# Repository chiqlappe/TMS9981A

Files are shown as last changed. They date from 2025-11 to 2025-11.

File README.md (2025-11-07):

# TMS9981Aビデオカード

## 概要
* PC-8001などからTMS9981Aを制御してビデオ出力を行うための拡張基板

## 使用環境
* PC-8001+PC-8012
* PC-8001mk2/SR
* PC-8801シリーズ（未確認）

## I/Oポート
|I/O|アドレス|用途|
|:--|:--|:--|
|IN/OUT|$98|データポート|
|IN/OUT|$99|コントロールポート|

## 参考サイト
[KUNINET BLOGさん](https://kuninet.org/2019/11/23/kz80%e3%83%9e%e3%82%a4%e3%82%b3%e3%83%b3-%e5%81%bdmsx1%e3%81%b8%e3%80%9c%e3%83%93%e3%83%87%e3%82%aa%e3%83%9c%e3%83%bc%e3%83%891/)

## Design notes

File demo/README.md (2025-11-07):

# デモプログラム

## 概要
* ビデオカードの動作検証用プログラム
* PC-8001シリーズ用
* 機械語プログラム（自動実行）

## プログラム
* ```ascii.wav``` フォント出力
* ```mandel.wav``` マンデルブロ集合
* ```nyan.wav``` Nyan Cat
* ```plasma.wav``` プラズマ
* ```sprite.wav``` スプライト
  
[J.B. Langston氏によるオリジナルプログラムはこちら](https://github.com/jblang/TMS9918A)

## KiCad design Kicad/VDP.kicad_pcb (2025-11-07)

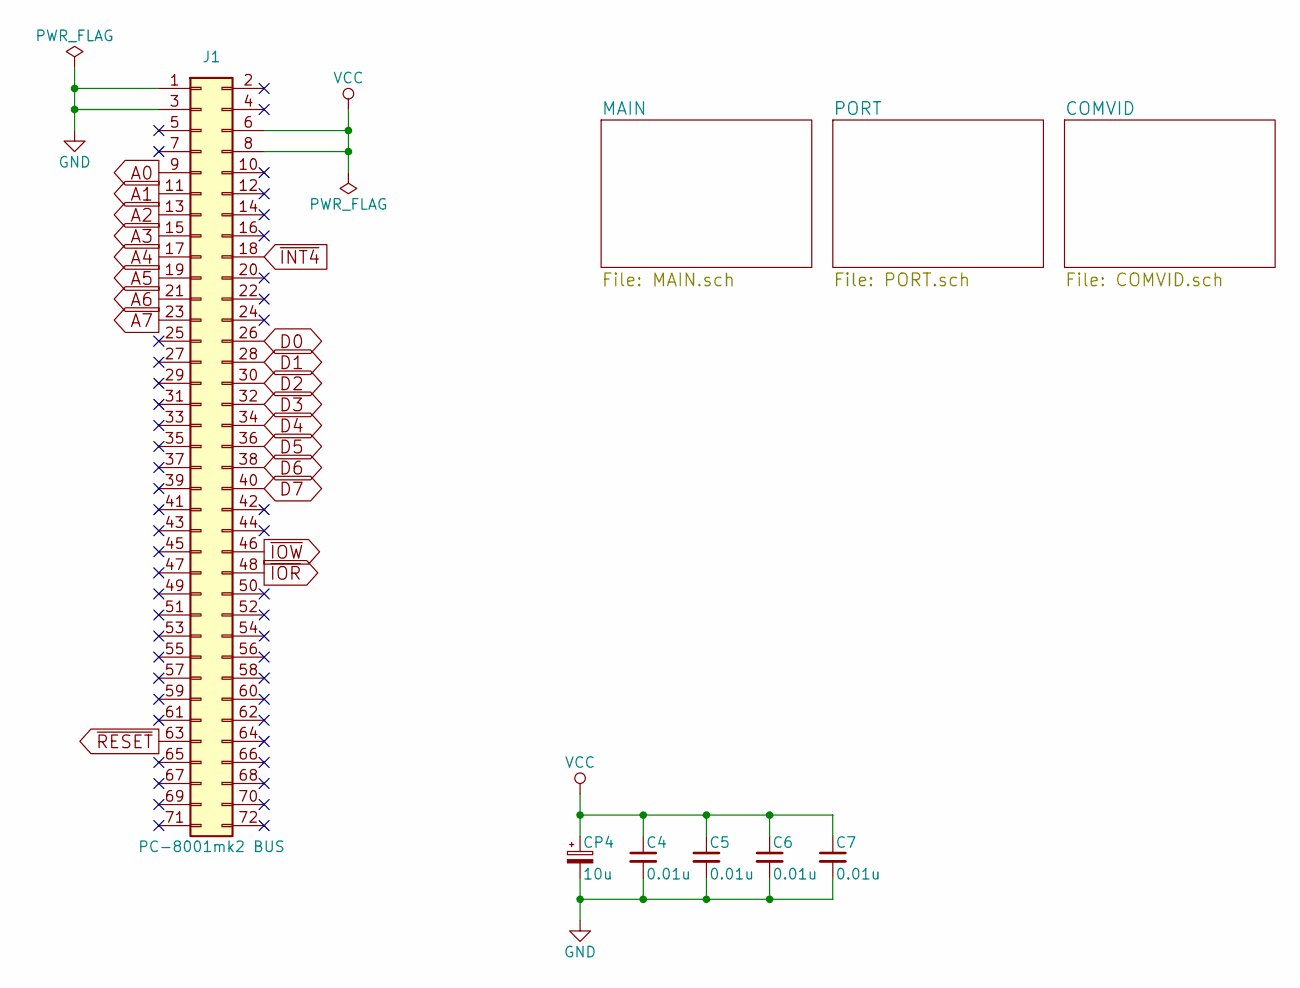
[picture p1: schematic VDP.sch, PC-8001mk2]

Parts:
C4, C5, C6, C7: 0.01u; C_Disc_D3.0mm_W1.6mm_P2.50mm
CP4: 10u; CP_Radial_D5.0mm_P2.50mm
J1: PC-8001mk2 BUS; PC88_72_ODD_EVEN

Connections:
A0: J1.9; also elsewhere on the board
A1: J1.11; also elsewhere on the board
A2: J1.13; also elsewhere on the board
A3: J1.15; also elsewhere on the board
A4: J1.17; also elsewhere on the board
A5: J1.19; also elsewhere on the board
A6: J1.21; also elsewhere on the board
A7: J1.23; also elsewhere on the board
D0: J1.26; also elsewhere on the board
D1: J1.28; also elsewhere on the board
D2: J1.30; also elsewhere on the board
D3: J1.32; also elsewhere on the board
D4: J1.34; also elsewhere on the board
D5: J1.36; also elsewhere on the board
D6: J1.38; also elsewhere on the board
D7: J1.40; also elsewhere on the board
GND: C4.2, C5.2, C6.2, C7.2, CP4.2, J1.1, J1.3; also elsewhere on the board
VCC: C4.1, C5.1, C6.1, C7.1, CP4.1, J1.6, J1.8; also elsewhere on the board
~INT4: J1.18; also elsewhere on the board
~IOR: J1.48; also elsewhere on the board
~IOW: J1.46; also elsewhere on the board
~RESET: J1.63; also elsewhere on the board

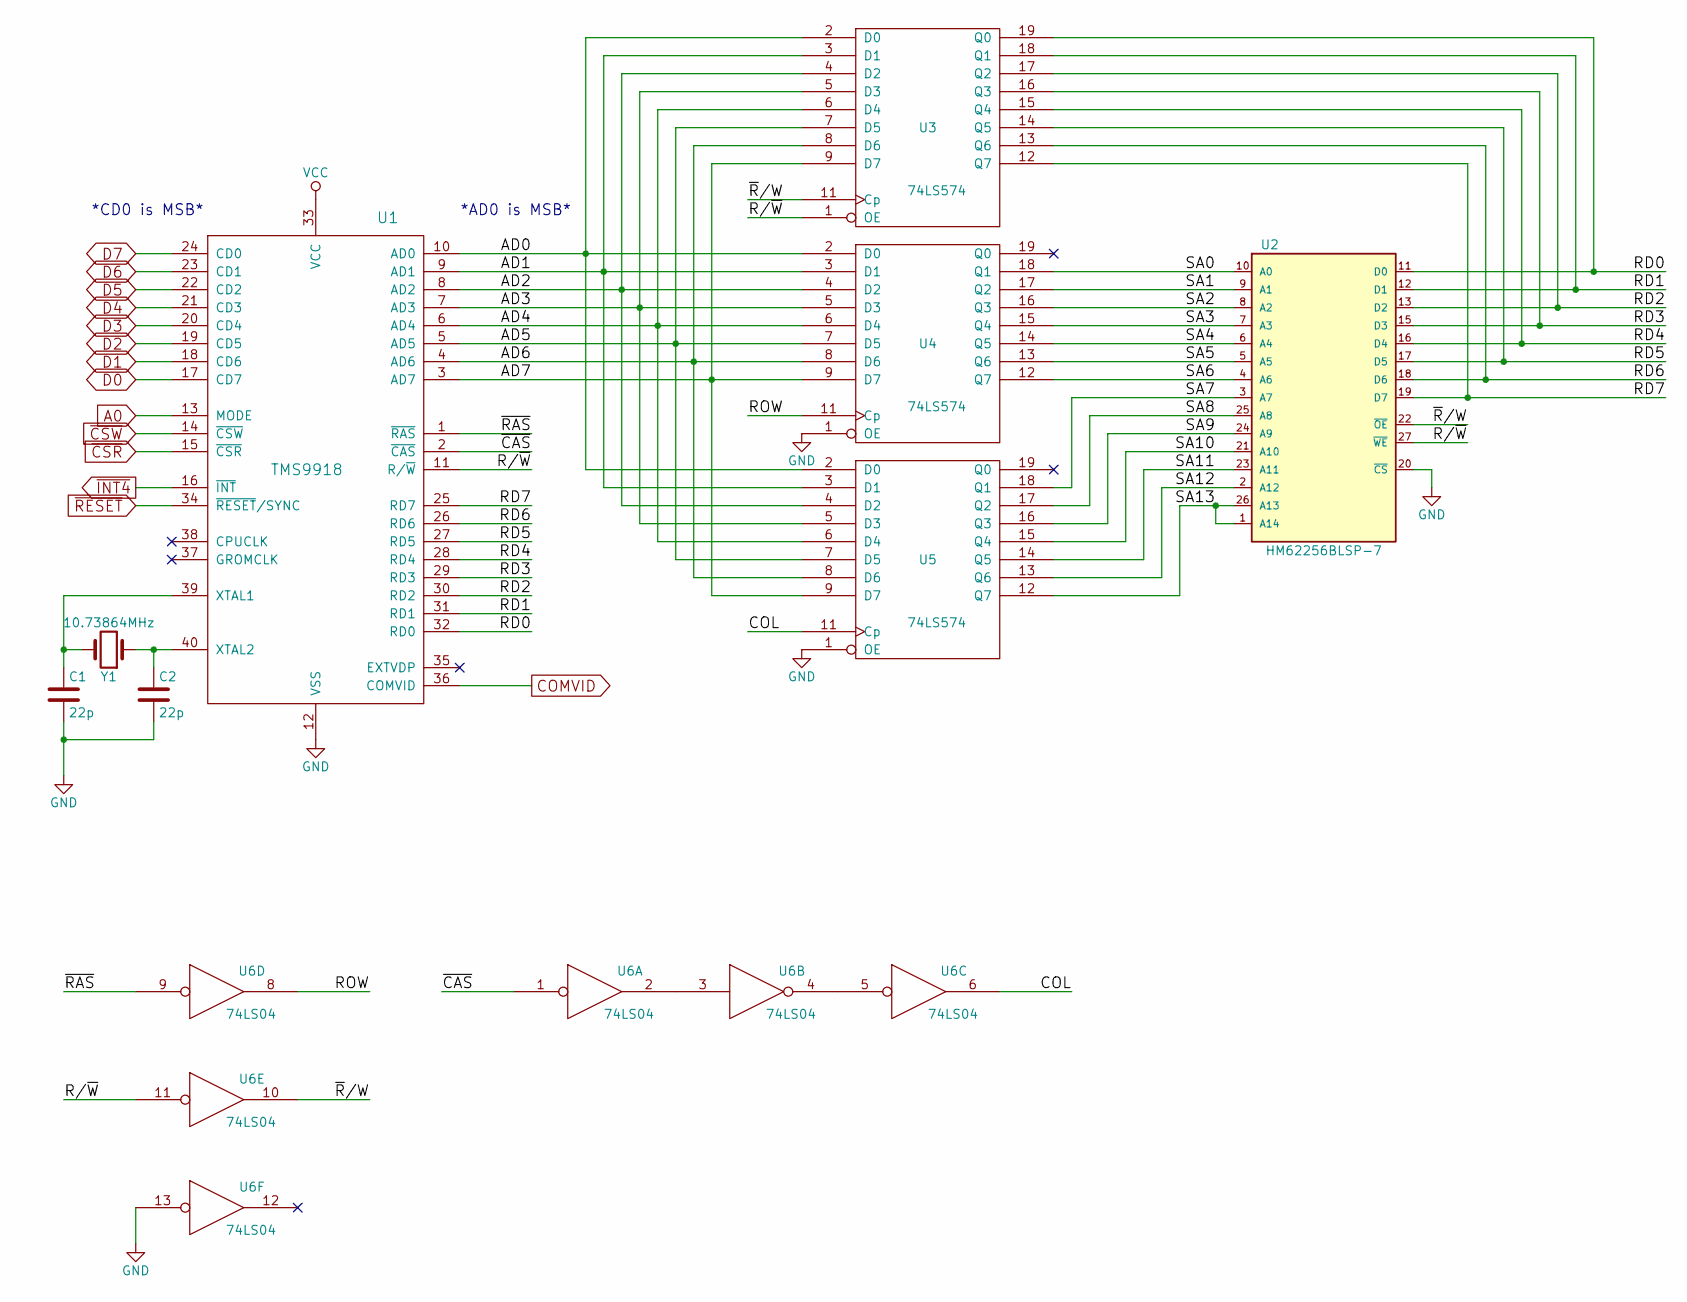
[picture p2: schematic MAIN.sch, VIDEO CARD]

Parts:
C1, C2: 22p; C_Disc_D3.0mm_W1.6mm_P2.50mm
U1: TMS9918; DIP-40_W15.24mm_Socket
U2: HM62256BLSP-7; DIP-28_W15.24mm_Socket
U3, U4, U5: 74LS574; DIP-20_W7.62mm_Socket
U6: 74LS04; DIP-14_W7.62mm_Socket
Y1: 10.73864MHz; Crystal_HC49-4H_Vertical

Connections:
/MAIN/AD0: U1.10 (AD0), U3.2 (D0), U4.2 (D0), U5.2 (D0)
/MAIN/AD1: U1.9 (AD1), U3.3 (D1), U4.3 (D1), U5.3 (D1)
/MAIN/AD2: U1.8 (AD2), U3.4 (D2), U4.4 (D2), U5.4 (D2)
/MAIN/AD3: U1.7 (AD3), U3.5 (D3), U4.5 (D3), U5.5 (D3)
/MAIN/AD4: U1.6 (AD4), U3.6 (D4), U4.6 (D4), U5.6 (D4)
/MAIN/AD5: U1.5 (AD5), U3.7 (D5), U4.7 (D5), U5.7 (D5)
/MAIN/AD6: U1.4 (AD6), U3.8 (D6), U4.8 (D6), U5.8 (D6)
/MAIN/AD7: U1.3 (AD7), U3.9 (D7), U4.9 (D7), U5.9 (D7)
/MAIN/COL: U5.11 (Cp), U6.6
/MAIN/R/~W: U1.11 (R/~W), U2.27 (~WE), U3.1 (OE), U6.11
/MAIN/RD0: U1.32 (RD0), U2.11 (D0), U3.19 (Q0)
/MAIN/RD1: U1.31 (RD1), U2.12 (D1), U3.18 (Q1)
/MAIN/RD2: U1.30 (RD2), U2.13 (D2), U3.17 (Q2)
/MAIN/RD3: U1.29 (RD3), U2.15 (D3), U3.16 (Q3)
/MAIN/RD4: U1.28 (RD4), U2.16 (D4), U3.15 (Q4)
/MAIN/RD5: U1.27 (RD5), U2.17 (D5), U3.14 (Q5)
/MAIN/RD6: U1.26 (RD6), U2.18 (D6), U3.13 (Q6)
/MAIN/RD7: U1.25 (RD7), U2.19 (D7), U3.12 (Q7)
/MAIN/ROW: U4.11 (Cp), U6.8
/MAIN/SA0: U2.10 (A0), U4.18 (Q1)
/MAIN/SA1: U2.9 (A1), U4.17 (Q2)
/MAIN/SA2: U2.8 (A2), U4.16 (Q3)
/MAIN/SA3: U2.7 (A3), U4.15 (Q4)
/MAIN/SA4: U2.6 (A4), U4.14 (Q5)
/MAIN/SA5: U2.5 (A5), U4.13 (Q6)
/MAIN/SA6: U2.4 (A6), U4.12 (Q7)
/MAIN/SA7: U2.3 (A7), U5.18 (Q1)
/MAIN/SA8: U2.25 (A8), U5.17 (Q2)
/MAIN/SA9: U2.24 (A9), U5.16 (Q3)
/MAIN/SA10: U2.21 (A10), U5.15 (Q4)
/MAIN/SA11: U2.23 (A11), U5.14 (Q5)
/MAIN/SA12: U2.2 (A12), U5.13 (Q6)
/MAIN/SA13: U2.1 (A14), U2.26 (A13), U5.12 (Q7)
/MAIN/~CAS: U1.2 (~CAS), U6.1
/MAIN/~RAS: U1.1 (~RAS), U6.9
/MAIN/~R~/W: U2.22 (~OE), U3.11 (Cp), U6.10
A0: U1.13 (MODE); also elsewhere on the board
COMVID: U1.36 (COMVID); also elsewhere on the board
D0: U1.17 (CD7); also elsewhere on the board
D1: U1.18 (CD6); also elsewhere on the board
D2: U1.19 (CD5); also elsewhere on the board
D3: U1.20 (CD4); also elsewhere on the board
D4: U1.21 (CD3); also elsewhere on the board
D5: U1.22 (CD2); also elsewhere on the board
D6: U1.23 (CD1); also elsewhere on the board
D7: U1.24 (CD0); also elsewhere on the board
GND: C1.2, C2.2, U1.12 (VSS), U2.14 (GND), U2.20 (~CS), U3.10 (GND), U4.1 (OE), U4.10 (GND), U5.1 (OE), U5.10 (GND), U6.7 (GND), U6.13; also elsewhere on the board
unnamed: C1.1, U1.39 (XTAL1), Y1.2
unnamed: C2.1, U1.40 (XTAL2), Y1.1
unnamed: U6.2, U6.3
unnamed: U6.4, U6.5
VCC: U1.33 (VCC), U2.28 (VCC), U3.20 (VCC), U4.20 (VCC), U5.20 (VCC), U6.14 (VCC); also elsewhere on the board
~CSR: U1.15 (~CSR); also elsewhere on the board
~CSW: U1.14 (~CSW); also elsewhere on the board
~INT4: U1.16 (~INT); also elsewhere on the board
~RESET: U1.34 (~RESET~/SYNC); also elsewhere on the board

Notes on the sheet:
*AD0 is MSB*
*CD0 is MSB*

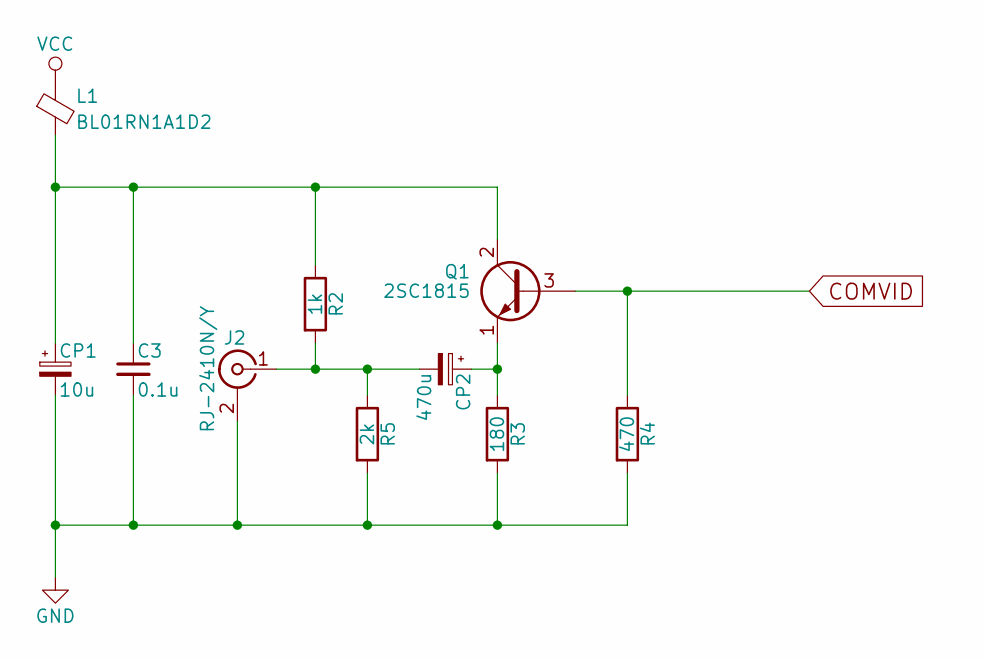
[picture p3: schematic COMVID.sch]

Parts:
C3: 0.1u; C_Disc_D3.0mm_W1.6mm_P2.50mm
CP1: 10u; CP_Radial_D5.0mm_P2.50mm
CP2: 470u; CP_Radial_D6.3mm_P2.50mm
J2: RJ-2410N/Y; RJ-2410N
L1: BL01RN1A1D2; R_Axial_DIN0204_L3.6mm_D1.6mm_P7.62mm_Horizontal
Q1: 2SC1815; TO-92_Inline_Wide
R2: 1k; R_Axial_DIN0204_L3.6mm_D1.6mm_P7.62mm_Horizontal
R3: 180; R_Axial_DIN0204_L3.6mm_D1.6mm_P7.62mm_Horizontal
R4: 470; R_Axial_DIN0204_L3.6mm_D1.6mm_P7.62mm_Horizontal
R5: 2k; R_Axial_DIN0204_L3.6mm_D1.6mm_P7.62mm_Horizontal

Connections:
COMVID: Q1.3 (B), R4.1; also elsewhere on the board
GND: C3.2, CP1.2, J2.2 (Ext), R3.2, R4.2, R5.2; also elsewhere on the board
unnamed: C3.1, CP1.1, L1.2, Q1.2 (C), R2.1
unnamed: CP2.1, Q1.1 (E), R3.1
unnamed: CP2.2, J2.1 (In), R2.2, R5.1
VCC: L1.1; also elsewhere on the board

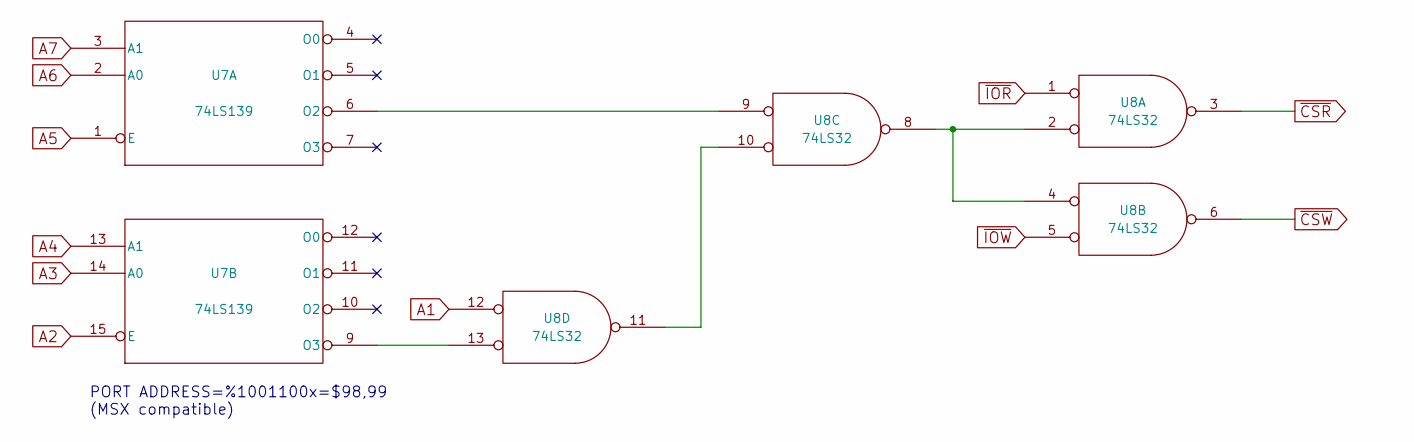
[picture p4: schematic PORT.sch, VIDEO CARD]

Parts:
U7: 74LS139; DIP-16_W7.62mm_Socket
U8: 74LS32; DIP-14_W7.62mm_Socket

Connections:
A1: U8.12; also elsewhere on the board
A2: U7.15 (E); also elsewhere on the board
A3: U7.14 (A0); also elsewhere on the board
A4: U7.13 (A1); also elsewhere on the board
A5: U7.1 (E); also elsewhere on the board
A6: U7.2 (A0); also elsewhere on the board
A7: U7.3 (A1); also elsewhere on the board
GND: U7.8 (GND), U8.7 (GND); also elsewhere on the board
unnamed: U7.6 (O2), U8.9
unnamed: U7.9 (O3), U8.13
unnamed: U8.2, U8.4, U8.8
unnamed: U8.10, U8.11
VCC: U7.16 (VCC), U8.14 (VCC); also elsewhere on the board
~CSR: U8.3; also elsewhere on the board
~CSW: U8.6; also elsewhere on the board
~IOR: U8.1; also elsewhere on the board
~IOW: U8.5; also elsewhere on the board

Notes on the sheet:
PORT ADDRESS=%1001100x=$98,99 (MSX compatible)

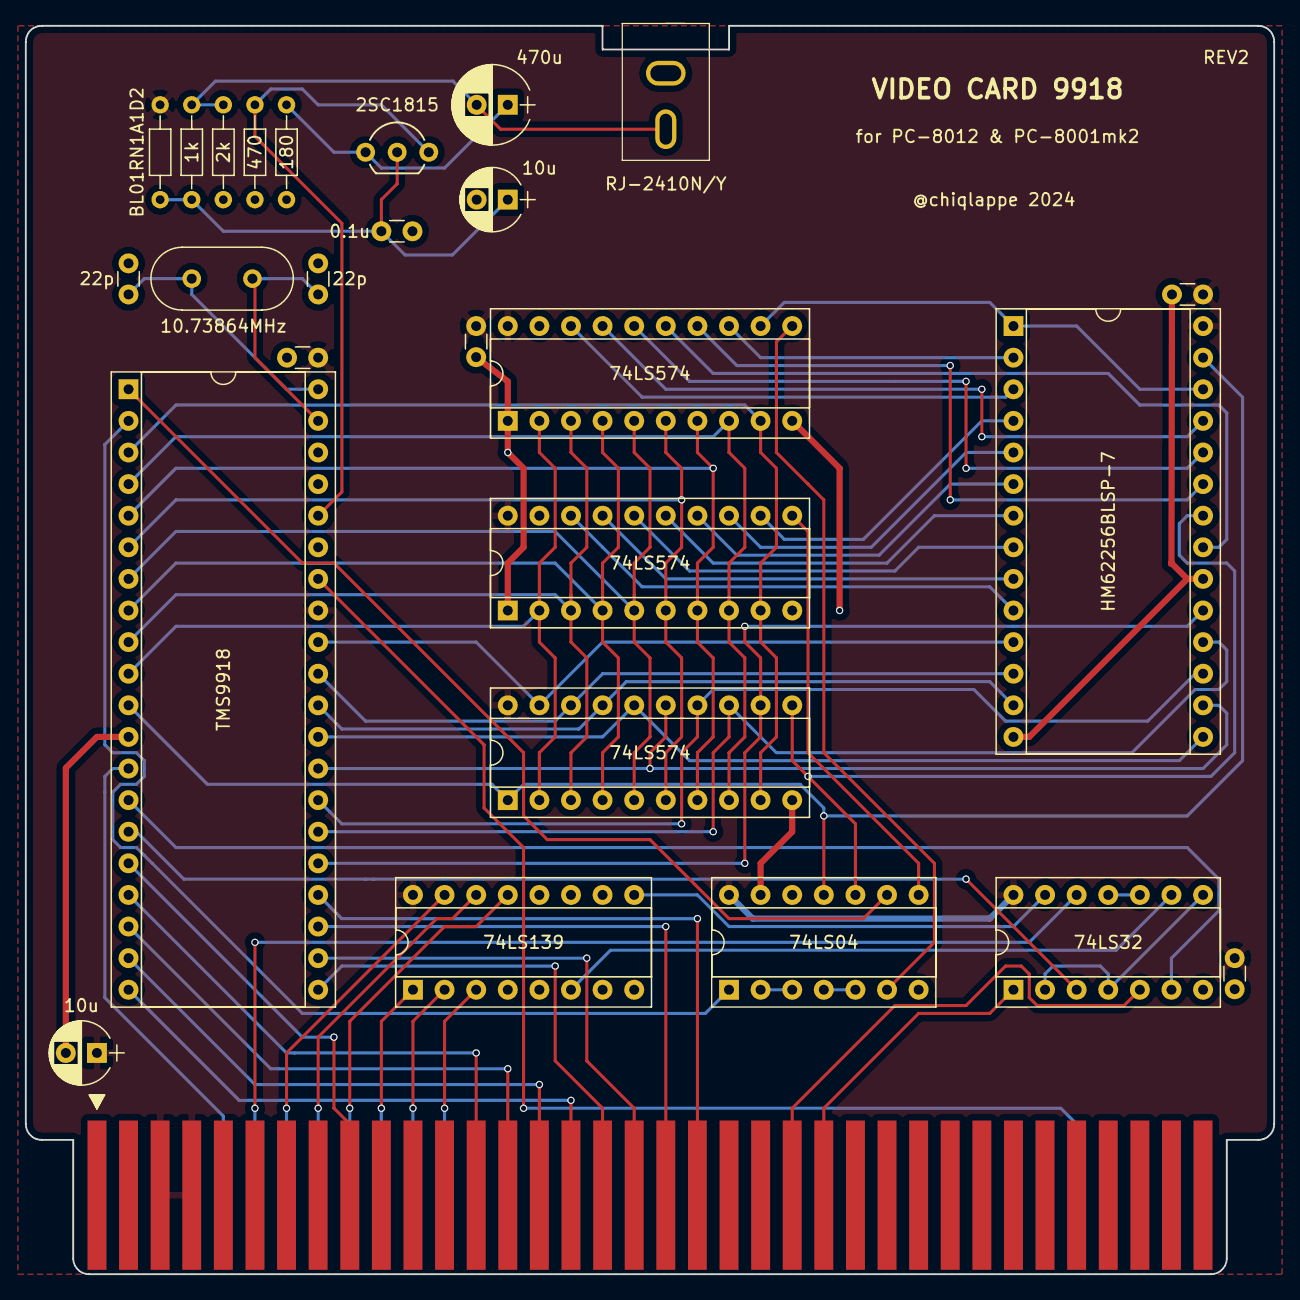
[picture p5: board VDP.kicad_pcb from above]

Board: 2 copper layers, 100.3 x 100.3 mm, 27 parts (0 on the bottom side), 72 nets.
